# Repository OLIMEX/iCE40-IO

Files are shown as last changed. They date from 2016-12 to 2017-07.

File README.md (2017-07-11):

# iCE40-IO

Extension module for iCE40HX1K-EVB or iCE40HX8K-EVB.

It is meant to make the input and output easier - the module provides video output connector VGA DE-15; 
keyboard connector PS2; infra red chip TFDU4100 for IrDA connectivity.

Typically, you would need only a signle iCE40-IO module in your setup. Using an iCE40-IO would reduce
the number of ADC and DAC expansion modules that you can use with a single iCE40HX1K-EVB or iCE40HX8K-EVB board.

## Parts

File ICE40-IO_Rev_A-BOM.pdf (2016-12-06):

ICE40-IO_Rev_A | 30.03.2016
Quantity Designation | Package | Designator
1 | VGA15-F(CD0515S21J0) | CD0515S21J0 | VGA1
3 | NA | R_0402 | R23,R1,R4
1 | 22uF/6.3V | C_0603 | C1
3 | 10k | R_0402 | R2,R21,R22
1 | NA(10k) | R_0402 | R3
2 | 100nF | C_0402 | C2,C3
2 | 5.6k | R_0402 | R10,R11
1 | 10nF | C_0402 | C4
1 | TFDU4100 | TFDU4100_PACK | IrDA1
1 | Opened | SJ | IRDA_LS_E1
3 | 470R | C_0603 | R8,R13,R17
3 | 1.8k | C_0603 | R12,R16,R20
3 | 1k | C_0603 | R15,R19,R9
2 | 47R | R_0805 | R5,R7
1 | 15R | R_1206 | R6
2 | 200R | R_0402 | R14,R18
1 | IDC34R | IDC34R/PCB | GPIO_In1
1 | BH34R | BH34R | GPIO_Out1
1 | MDR6_MINI-DIN | PS2_MDR6_MINI-DIN | PS2_KEYBOARD1

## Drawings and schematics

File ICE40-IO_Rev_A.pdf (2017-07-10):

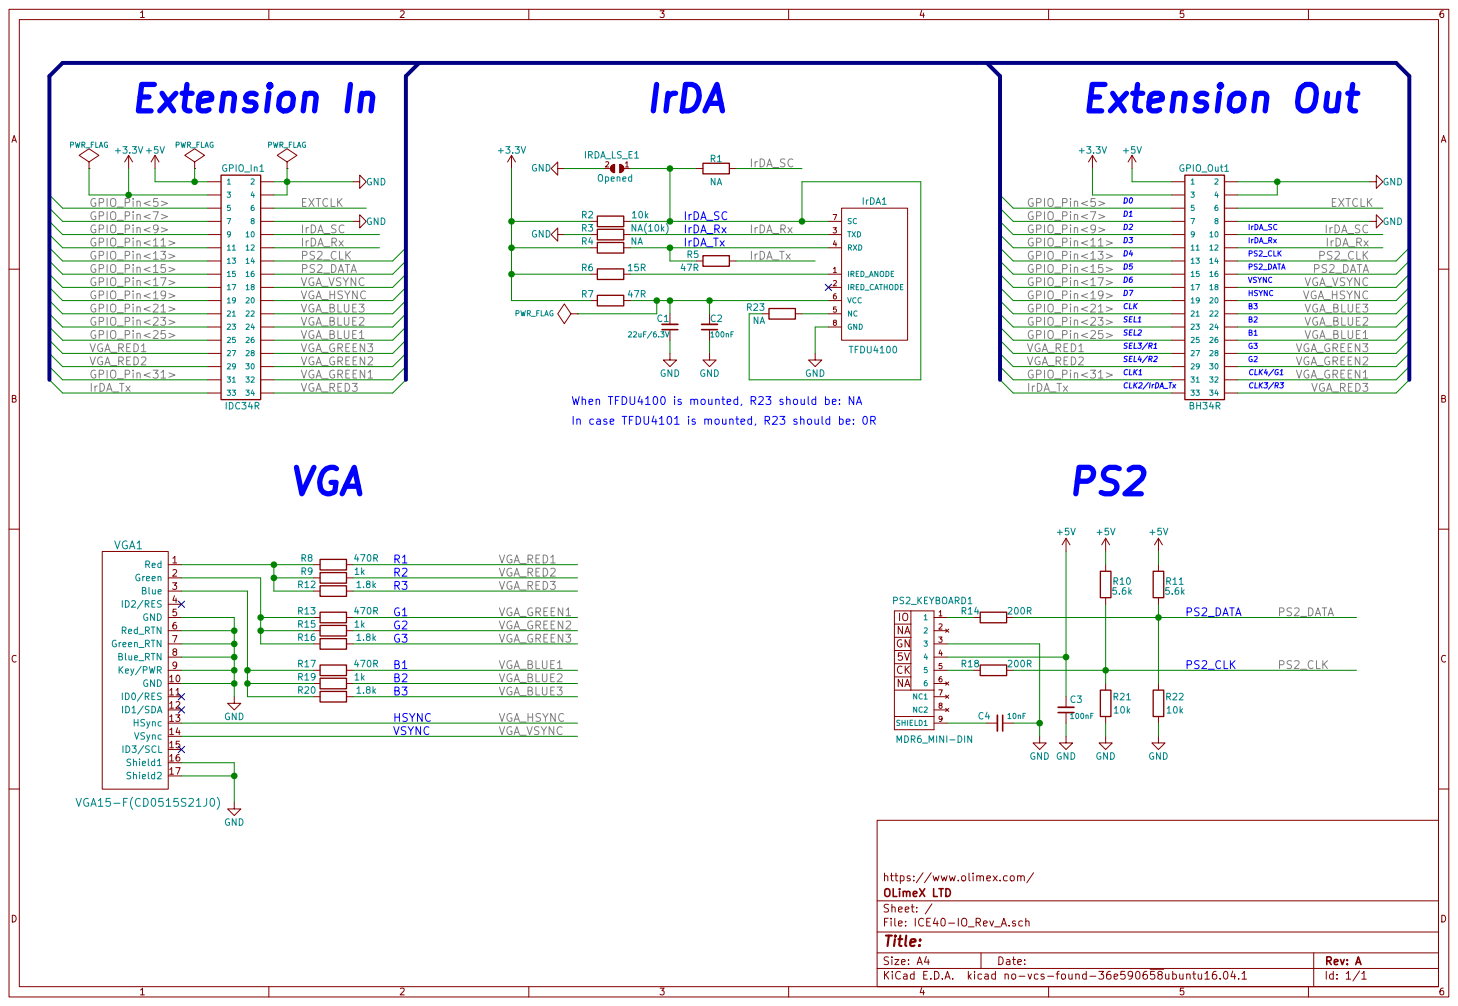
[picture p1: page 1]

R23 NA When TFDU4100 is mounted, R23 should be: NA

VGA_BLUE3
VGA_BLUE2
VGA_BLUE1

In case TFDU4101 is mounted, R23 should be: 0R

https://www.olimex.com/
File: ICE40-IO_Rev_A.sch Sheet: / OLimeX LTD

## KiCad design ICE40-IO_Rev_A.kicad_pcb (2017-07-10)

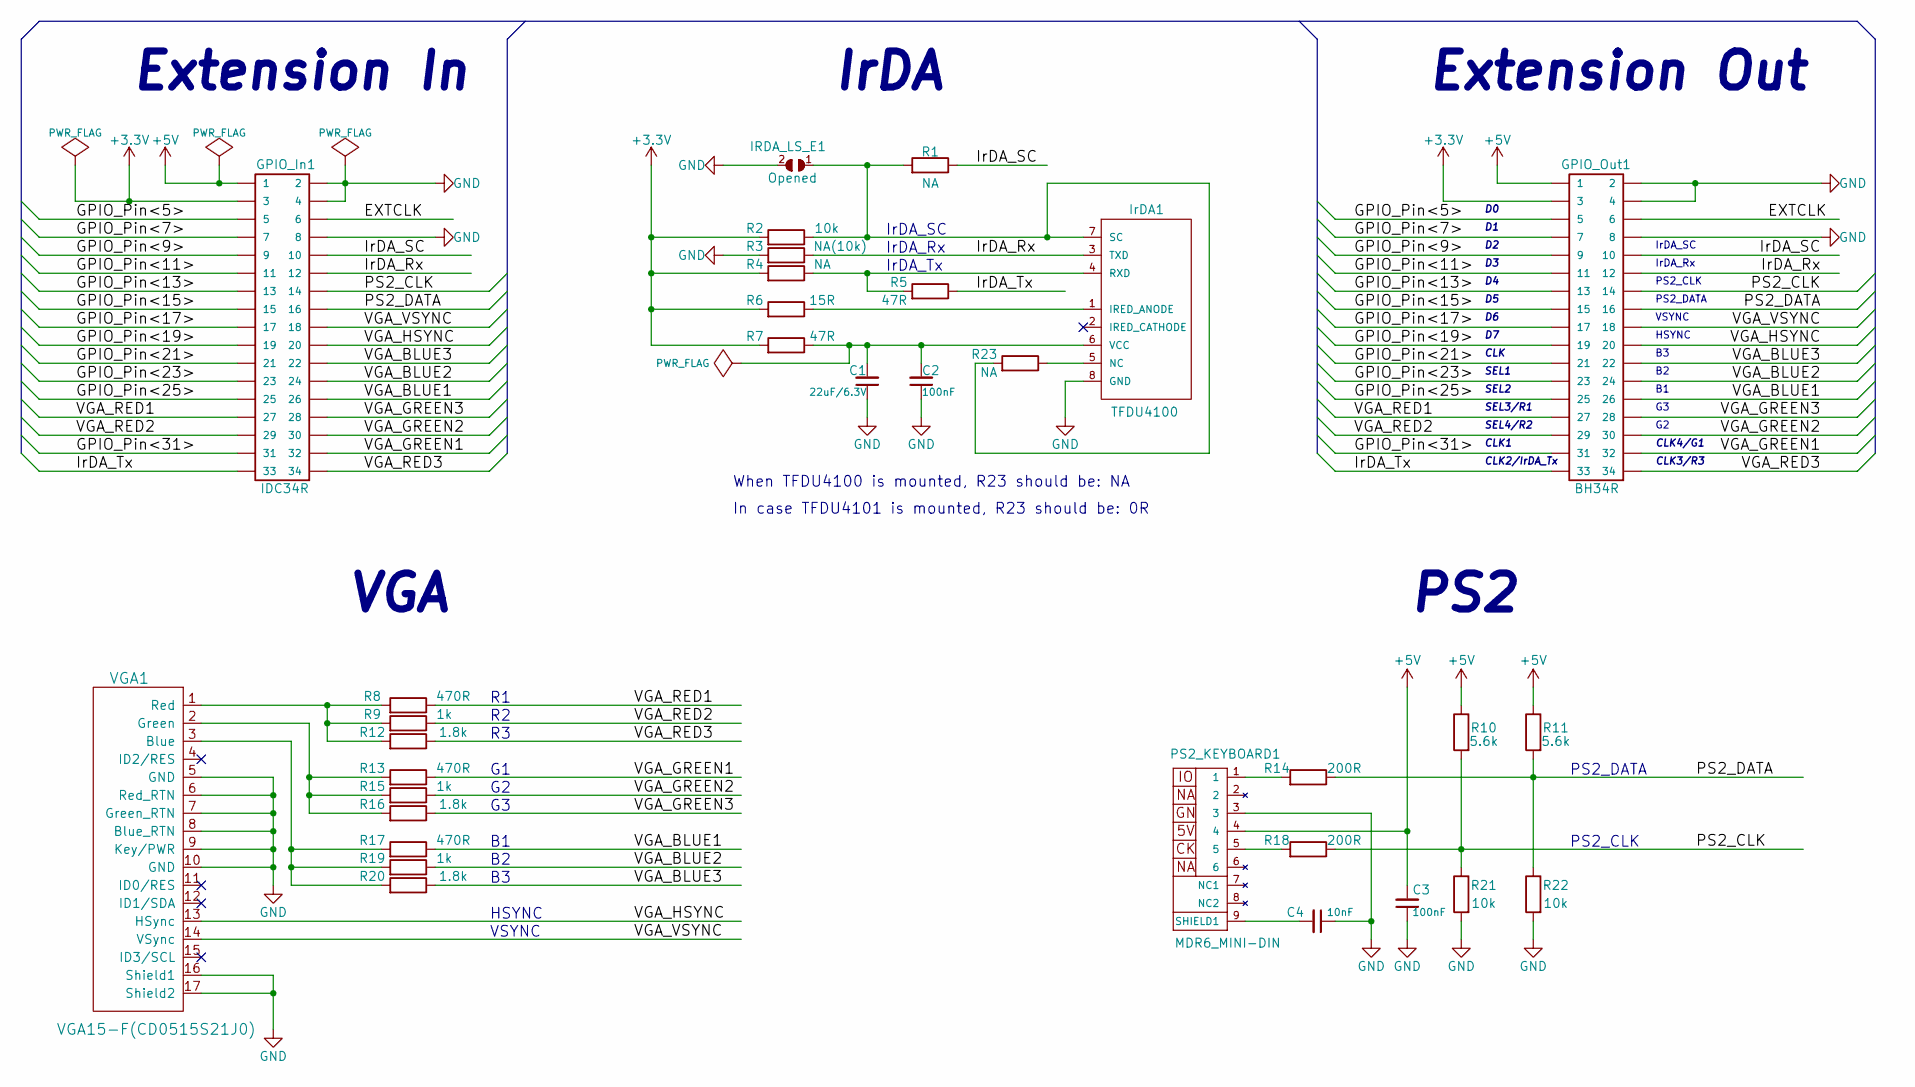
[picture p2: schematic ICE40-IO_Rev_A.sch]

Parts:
C1: 22uF/6.3V; C_0603_5MIL_DWS
C2, C3: 100nF; C_0402_5MIL_DWS
C4: 10nF; C_0402_5MIL_DWS
GPIO_In1: IDC34R; IDC34R_PCB
GPIO_Out1: BH34R
IRDA_LS_E1: Opened; SJ
IrDA1: TFDU4100; TFDU4100_PACK
PS2_KEYBOARD1: MDR6_MINI-DIN; PS2_MDR6_MINI-DIN
R1, R4, R23: NA; R_0402_5MIL_DWS
R2, R21, R22: 10k; R_0402_5MIL_DWS
R3: NA(10k); R_0402_5MIL_DWS
R5, R7: 47R; R_0805_5MIL_DWS
R6: 15R; R_1206_5MIL_DWS
R8, R13, R17: 470R; C_0603_5MIL_DWS
R9, R15, R19: 1k; C_0603_5MIL_DWS
R10, R11: 5.6k; R_0402_5MIL_DWS
R12, R16, R20: 1.8k; C_0603_5MIL_DWS
R14, R18: 200R; R_0402_5MIL_DWS
VGA1: VGA15-F(CD0515S21J0)

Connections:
+3V3: GPIO_In1.3, GPIO_Out1.3, R2.2, R4.2, R6.2, R7.2
+5V: C3.2, GPIO_In1.1, GPIO_Out1.1, PS2_KEYBOARD1.4, R10.1, R11.1
/EXTCLK: GPIO_In1.6, GPIO_Out1.6
/GPIO_Pin<5>: GPIO_In1.5, GPIO_Out1.5
/GPIO_Pin<7>: GPIO_In1.7, GPIO_Out1.7
/GPIO_Pin<9>: GPIO_In1.9, GPIO_Out1.9
/GPIO_Pin<11>: GPIO_In1.11, GPIO_Out1.11
/GPIO_Pin<13>: GPIO_In1.13, GPIO_Out1.13
/GPIO_Pin<15>: GPIO_In1.15, GPIO_Out1.15
/GPIO_Pin<17>: GPIO_In1.17, GPIO_Out1.17
/GPIO_Pin<19>: GPIO_In1.19, GPIO_Out1.19
/GPIO_Pin<21>: GPIO_In1.21, GPIO_Out1.21
/GPIO_Pin<23>: GPIO_In1.23, GPIO_Out1.23
/GPIO_Pin<25>: GPIO_In1.25, GPIO_Out1.25
/GPIO_Pin<31>: GPIO_In1.31, GPIO_Out1.31
/IrDA_Rx: GPIO_In1.12, GPIO_Out1.12, IrDA1.3 (TXD), R3.1
/IrDA_SC: GPIO_In1.10, GPIO_Out1.10, R1.1
/IrDA_Tx: GPIO_In1.33, GPIO_Out1.33, R5.1
/PS2_CLK: GPIO_In1.14, GPIO_Out1.14, R10.2, R18.1, R21.1
/PS2_DATA: GPIO_In1.16, GPIO_Out1.16, R11.2, R14.1, R22.1
/VGA_BLUE1: GPIO_In1.26, GPIO_Out1.26, R17.1
/VGA_BLUE2: GPIO_In1.24, GPIO_Out1.24, R19.1
/VGA_BLUE3: GPIO_In1.22, GPIO_Out1.22, R20.1
/VGA_GREEN1: GPIO_In1.32, GPIO_Out1.32, R13.1
/VGA_GREEN2: GPIO_In1.30, GPIO_Out1.30, R15.1
/VGA_GREEN3: GPIO_In1.28, GPIO_Out1.28, R16.1
/VGA_HSYNC: GPIO_In1.20, GPIO_Out1.20, VGA1.13 (HSync)
/VGA_RED1: GPIO_In1.27, GPIO_Out1.27, R8.1
/VGA_RED2: GPIO_In1.29, GPIO_Out1.29, R9.1
/VGA_RED3: GPIO_In1.34, GPIO_Out1.34, R12.1
/VGA_VSYNC: GPIO_In1.18, GPIO_Out1.18, VGA1.14 (VSync)
GND: C1.1, C2.1, C3.1, C4.1, GPIO_In1.2, GPIO_In1.4, GPIO_In1.8, GPIO_Out1.2, GPIO_Out1.4, GPIO_Out1.8, IRDA_LS_E1.2, IrDA1.8 (GND), PS2_KEYBOARD1.3, R3.2, R21.2, R22.2, VGA1.5 (GND), VGA1.6 (Red_RTN), VGA1.7 (Green_RTN), VGA1.8 (Blue_RTN), VGA1.9 (Key/PWR), VGA1.10 (GND), VGA1.16 (Shield1), VGA1.17 (Shield2)
unnamed: C1.2, C2.2, IrDA1.6 (VCC), R7.1
unnamed: C4.2, PS2_KEYBOARD1.9 (SHIELD1)
unnamed: IRDA_LS_E1.1, IrDA1.7 (SC), R1.2, R2.1, R23.2
unnamed: IrDA1.1 (IRED_ANODE), R6.1
unnamed: IrDA1.4 (RXD), R4.1, R5.2
unnamed: IrDA1.5 (NC), R23.1
unnamed: PS2_KEYBOARD1.1, R14.2
unnamed: PS2_KEYBOARD1.5, R18.2
unnamed: R8.2, R9.2, R12.2, VGA1.1 (Red)
unnamed: R13.2, R15.2, R16.2, VGA1.2 (Green)
unnamed: R17.2, R19.2, R20.2, VGA1.3 (Blue)

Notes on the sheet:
Extension Out
Extension In
CLK
SEL1
SEL2
SEL3/R1
SEL4/R2
CLK1
CLK2/IrDA_Tx
CLK3/R3
CLK4/G1
HSYNC
VSYNC
PS2_CLK
PS2_DATA
IrDA_Rx
IrDA_Tx
IrDA_SC
IrDA
VGA
PS2
When TFDU4100 is mounted, R23 should be: NA
In case TFDU4101 is mounted, R23 should be: 0R

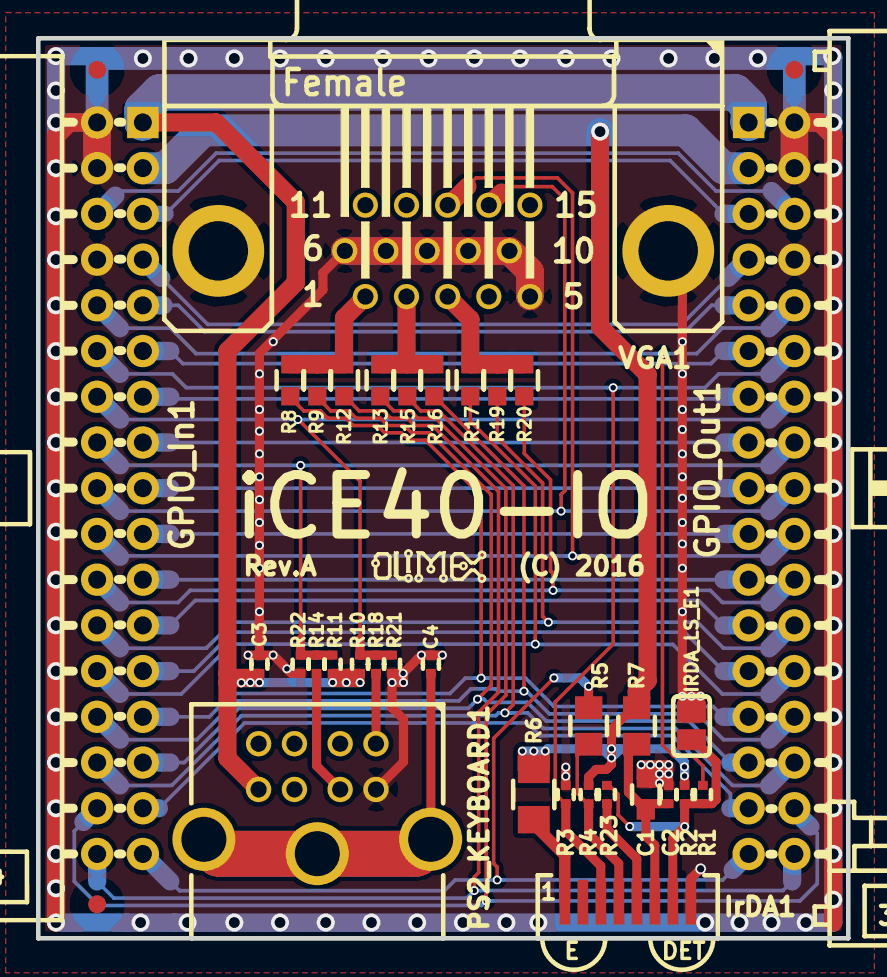
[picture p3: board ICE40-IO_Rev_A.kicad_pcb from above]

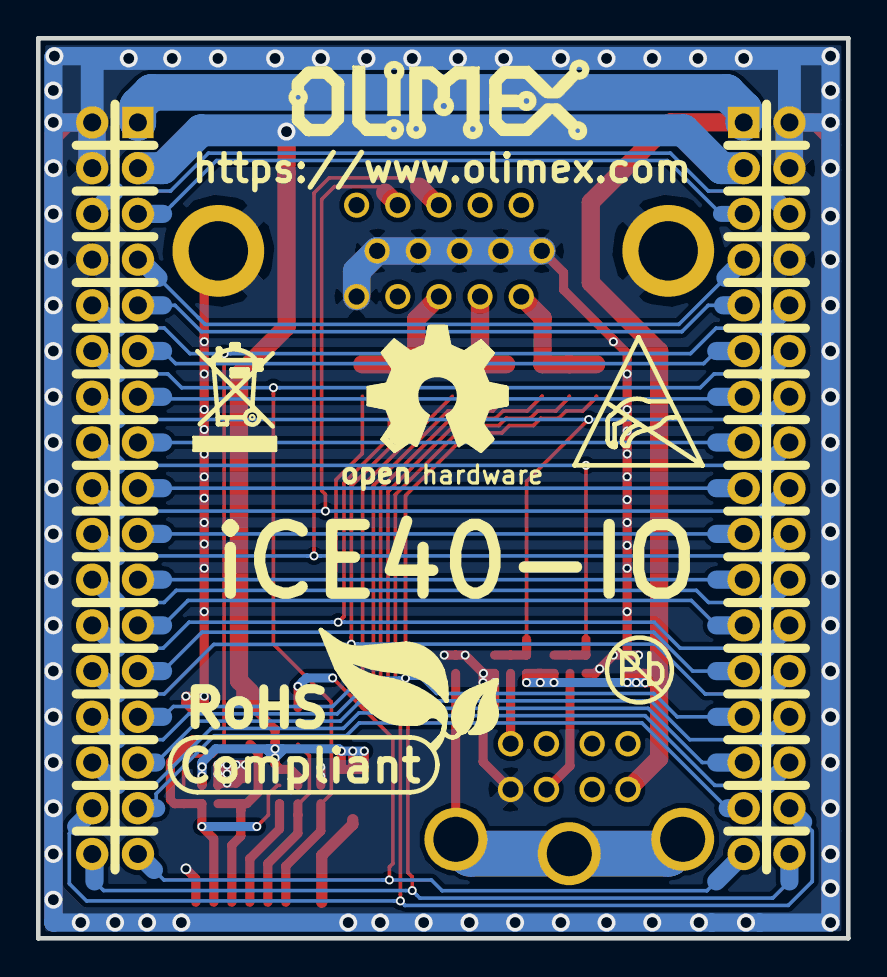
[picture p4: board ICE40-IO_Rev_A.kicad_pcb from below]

Board: 2 copper layers, 45.0 x 50.0 mm, 35 parts (2 on the bottom side), 43 nets.

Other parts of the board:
Ref**: Val**; LOGO_ROHS_1
Ref**#2: Val**; LOGO_ANTISTATIC_1

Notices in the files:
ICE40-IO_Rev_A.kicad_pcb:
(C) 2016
